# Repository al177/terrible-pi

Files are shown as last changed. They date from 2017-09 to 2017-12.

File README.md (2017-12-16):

# terrible-pi

 

*A supercomputer, but fun sized. And not super.*

In this repo you'll find hardware designs for the Terrible-Pi, a cluster
computer made from four Raspberry Pi Zero boards used as compute elements
and one Raspberry Pi Zero W as a head node and network router.

terrible-pi is based around a USB backplane that powers and interconnects
all five Pi Zeros and allows the head node to control power to each of the
compute nodes.  The USB boot feature of the Pi Zero is used to automate
deployment of new OS images to each compute node.

Up to date news on this project can be found at [this Hackaday project.](https://hackaday.io/project/27142-terrible-cluster)

Repo Contents
-------------
The terrible_pcb directory has a board design for the backplane and a 3D printable case.  See terrible_pcb/README for instructions for printing the case and the backplane board.

`etc` contains config files to be copied on top of the Raspbian install for
the head node.

wpa_supplicant.conf is a template WiFi config for the head node.  This is used
for headless setup of the head node Raspbian SD card for remote SSH access.

`nodeimg_build.sh` is a script for extracting a Raspbian distribution image into
a set of files used to deploy new compute nodes.

`node_init.sh` is a script used to upload the compute node Raspbian generated
by `nodeimg_build.sh` to the SD card of a compute node.

terrible-pi Install and Usage Guide
===================================

Setting up a terrible-pi cluster head node
------------------------------------------

1. Get the latest Raspbian (https://downloads.raspberrypi.org/raspbian_lite_latest)
   and install to a microSD
   
2. Mount the first (FAT) partition of the card on a PC.
		
3. Copy "wpa_supplicant.conf" from this repo to the card.  Edit it so that
   "YOUR_SSID" is replaced by the WiFi network name that you want the head node
   to connect to, and "YOUR_PASSPHRASE" is replaced by the network's key.  Use
   your Google-fu if you can't get it to work.
		
4. Create an empty file on the card named "ssh".  Use the UNIX command "touch
   ssh" or just open and save a new file "ssh" with your text editor.
		
5. Boot the microSD on the Pi Zero W
		
6. After 4-5 minutes, try SSHing as "pi" to the Zero W with the hostname
   "raspberrypi", "raspberrypi.lan", or "raspberrypi.local".  Use the password
   "raspberry".  If your router isn't serving DNS for local domains, you may
   have to check the router's DHCP lease logs to see what IP the head node has.
		
7. Now that you're logged into the Pi Zero W, update to the latest Raspbian
   packages:

```
sudo apt-get -y update && sudo apt-get -y upgrade
```
			
8. Install the necessary packages:
			
```
sudo apt-get -y install libusb-1.0-0-dev nfs-kernel-server git \
pdsh udhcpd iptables bridge-utils
```
9. Build and install the USB hub tool:

```
cd
git clone https://github.com/mvp/uhubctl.git
pushd uhubctl
make
sudo cp uhubctl /usr/local/bin/.
sudo chown root:root /usr/local/bin/uhubctl
popd
```
10. Build and install the USB boot tool:
	
```
git clone https://github.com/raspberrypi/usbboot.git
pushd usbboot
make
sudo cp rpiboot /usr/local/bin/.
sudo mkdir /usr/share/rpiboot
sudo cp -a msd /usr/share/rpiboot
sudo chown -R root:root /usr/share/rpiboot
sudo chown -R root:root /usr/local/bin/rpiboot
popd
```
11. Get this repo on the Pi:

```
git clone https://github.com/al177/terrible-pi.git
```

12. Copy the config files for the DHCP server, networks, NFS, SSH, and
hosts, hostname, and startup scripts:

```
sudo chown -R root:root /home/pi/terrible-pi/etc			
sudo cp -a /home/pi/terrible-pi/etc/* /etc/.
```		
13. Enable necessary services:

```
sudo systemctl enable udhcpd
sudo systemctl enable rpcbind
sudo systemctl enable nfs-kernel-server
```
14. Create an NFS directory for the clients:

```
sudo mkdir /srv/pihome
sudo chown pi:pi /srv/pihome
chmod 755 /srv/pihome
mkdir /srv/pihome/.ssh
chmod 700 /srv/pihome/.ssh
```

15. Reboot the head node.

16. SSH to the head node again. The config files copied over have changed the
    hostname to "head".  So if you connected as "raspberrypi.lan",
    "raspberrypi", or "raspberrypi.local" above, use "head.lan", "head", or
    "head.local" when reconnecting.

17. Make an empty passphrase SSH key so the head can automatically connect to
    the nodes:

```
ssh-keygen -t rsa -f /srv/pihome/.ssh/terrible.rsa -N ""
cp /srv/pihome/.ssh/terrible.rsa.pub /srv/pihome/.ssh/authorized_keys
chmod 600 /srv/pihome/.ssh/authorized_keys
mkdir -p ~/.ssh
chmod 700 ~/.ssh
cp /srv/pihome/.ssh/terrible.rsa ~/.ssh/.
```

Setting up terrible cluster compute nodes
-----------------------------------------

### Creating the compute node filesystem

1. Get the Raspbian Lite zip file on the head node in /home/pi.  This can be
   the zip used to create the head node microSD card, or can be downloaded by:

```
wget --trust-server-names https://downloads.raspberrypi.org/raspbian_lite_latest
```
	 
Note the filename that it downloads as.

2. Prep the boot image:

```
sudo terrible-pi/nodeimg_build.sh 2017-09-07-raspbian-stretch-lite.zip
```
	
This will take 10-15 minutes.  The result will be a directory "tcboot"
that contains the boot files and filesystems for the nodes.  This process
needs to be repeated only when changing or upgrading the Raspbian install on
the compute nodes.

### Deploying Raspbian to the compute nodes

1. Insure that the microSD cards in nodes do not contain the Raspberry Pi
   bootloader, or the USB boot method used to manage this cluster will not work.
   Insure that "bootcode.bin" does not exist in the root of any of the
   partitions on any of the cards.  If in doubt, do a full erase on the SD card
   to wipe out the bootloader in any of the partitions.
	 
2. Turn off all the nodes.  If the nodes all power up in bootstrap mode
   simultaneously, the image transfer script won't work.

```
sudo uhubctl -r 4 -a off
```

3. Transfer the SD filesystem to each node, looping over all nodes in series:

```
for N in 1 2 3 4; do sudo terrible-pi/node_init.sh tcboot $N; done
```

This takes 5-10 minutes per node depending on the speed of the SD cards
on the compute node Pi Zeros.

Terrible cluster management
---------------------------

### Booting the cluster

To boot the compute nodes, first start the rpiboot server in another
terminal session:

```
sudo rpiboot -o -l -d /home/pi/tcboot
```

Then cycle power on all of the nodes:

```
sudo uhubctl -r 4 -a cycle
```

The boot will take 2-3 minutes.  The nodes should be pingable once they are
done.  

### Connecting to the nodes

Before SSHing to a node in any given session, start the key agent and add
the SSH key:

```
eval `ssh-agent`
ssh-add ~/.ssh/terrible.rsa
```

You can SSH to a node by name:

```
ssh node1
```

Or you can run a command on all nodes with pdsh:

```
pdsh -R ssh -w node1,node2,node3,node4 hostname
```

Raspberry Pi Zero 1.3 models
[pi0computer.stl and pi0sdcard.stl](https://www.thingiverse.com/thing:2101674)
are created by jdhorvat and licensed CC-BY-NC.  [OpenSCAD parametric fan model](https://www.thingiverse.com/thing:625905) is created by GelatinousSlime and licensed CC-BY-SA. All other files in this tree are by Andrew Litt and licensed as 
[CC-BY-SA.](https://creativecommons.org/licenses/by-sa/4.0/)

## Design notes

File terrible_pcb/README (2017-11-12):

Hardware design for the Terrible Cluster.

1) Backplane board

terrible.pro is the KiCad project for the Terrible Cluster backplane board.  All components needed to create fabbable output are in this project, however due to license restrictions the 3D models needed to render the assembly are not included.

Pre-built gerbers for the v0.1 release of the board are in the directory gerber_v0.1.  These are fab-ready and can be zipped and sent off as-is.

terrible_v1a_bom.csv is a CSV format BOM for the backplane.  It can be imported to a Digi-Key cart for convenience.

BOM history
-----------
v1  - Initial BOM for PCB v0.1
v1a - Corrected microUSB B to match the current footprint, add insulator
      spacer for crystal Y1

After assembling the backplane, flush cut all of the through hole pins to under 1mm, or it may not fit in the case.

2) Case

terrible_case.scad is an OpenSCAD model for a 3D printed enclosure for the Terrible Cluster.  It is a single piece into which the backplane and Zero nodes can slide.  A 40mm x 40mm x 10mm 5V fan is friction-fit into the open end, and provides cooling for the cluster.  The cluster board assembly is held in place by a piece of 1.75mm filament fed through holes at the open side of the backplane PCB channel.

terrible_case.stl is a printable file for the case rendered from terrible_case.scad.  This case is sensitive to printer tolerances, so if parts of the case print too tight or loose, it may be necessary to customize the SCAD file and regenerate the .stl.

The fan is wired to the two pin power pads on the backplane.  A 2x1 0.1" right angle header can be soldered to the pads, and a matching plug attached to the fan leads if desired, or the fan can be soldered directly to the pads.  Care should be taken to reduce slack in the fan cable to prevent any loose wire from interfering with the fan.

When sliding the cluster into the case, it may be necessary to move the Zeros side to side to get them to all fit in the slot cutouts.  It should not take much force to get the backplane to slide in all the way.

After the cluster is in the case, feed a piece of 1.75mm filament through both holes towards the back of the case.  Use flush cutters to clip the filament even with the side of the case on both sides.  This will prevent the cluster from sliding backwards into the fan, especially when inserting a microUSB power cable.  To take apart the cluster, push the filament through with a paperclip and pull it out from the other side.

The fan uses a friction fit to hold it in the back of the case.  Exact outer dimensions of these fans can vary slightly, so the fan cutout is intentionally slightly oversized.  Use a piece of folded paper or layers of tape on one side of the fan as a shim to secure the fan.

The SCAD file can render the case alone in an orientation for printing, or render the case along with a model of the cluster and the fan to show the finished cluster.  Set "PRODUCTION=true" near the top of the SCAD to render for printing, and "PRODUCTION=false" to render the internal parts as well.

3) Cluster model

terrible.scad is an OpenSCAD model of the backplane board and the Raspberry Pi Zeros.  It is used as part of the case model for checking fitment and to render a completed Terrible Cluster.  Load it into OpenSCAD on its own to render the cluster boards.

Attributions:

-Raspberry Pi Zero model by MisterC from https://www.thingiverse.com/thing:1638529 for the 3D model.

-OpenSCAD parametric fan model by GelatinousSlime from https://www.thingiverse.com/thing:625905 for the case model.

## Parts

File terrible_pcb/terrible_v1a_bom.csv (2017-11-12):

Digi-Key Part Number | Manufacturer | Manufacturer Part Number | Customer Reference | Quantity 1 | Quantity 2 | Quantity 3 | Mfg Std Lead Time | Description | Comments | RoHS Status | Lead Free Status | REACH Status
H125237-ND | HIROSE ELECTRIC CO LTD | ZX20-B-5S-UNIT(30) | P1 | 5 | 0 | 0 | 8 Weeks | CONN PLUG USB MICRO B PCB VERT |  | RoHS Compliant | Lead free | Not Available
H11496CT-ND | HIROSE ELECTRIC CO LTD (VA) | ZX20-B-SLDC | P1 | 5 | 0 | 0 | 8 Weeks | SHIELDING PLATE FOR ZX20 PLUG | Alternate Packaging Exists | RoHS Compliant | Lead free | Not Available
428-3155-1-ND | CYPRESS SEMICONDUCTOR CORP (VA) | CY7C65632-48AXCT | U1 | 1 | 0 | 0 | 15 Weeks | IC CONTROLLER USB 48TQFP | Alternate Packaging Exists | RoHS Compliant | Lead free | Unaffected Jul-2017
AP2191DWG-7DICT-ND | DIODES INCORPORATED (VA) | AP2191DWG-7 | U2 | 4 | 0 | 0 | 12 Weeks | IC PWR SW USB SOT25 | Alternate Packaging Exists | RoHS Compliant | Lead free | Unaffected Jan-2017
P964-ND | PANASONIC ELECTRONIC COMPONENTS | ECE-A1AKS221 | C1 | 4 | 0 | 0 | 15 Weeks | CAP ALUM 220UF 20% 10V RADIAL |  | RoHS Compliant | Lead free | Unaffected Jun-2016
WM1399CT-ND | MOLEX, LLC (VA) | 1050170001 | P6 | 1 | 0 | 0 | 17 Weeks | CONN RCPT MICRO USB R/A SMD | Alternate Packaging Exists | RoHS Compliant | Lead free | Unaffected Jun-2016
535-9037-ND | ABRACON LLC | ABL-12.000MHZ-B2 | Y1 | 1 | 0 | 0 | 9 Weeks | CRYSTAL 12.0000MHZ 18PF T/H |  | RoHS Compliant | Lead free | Affected Jan-2017
311-1088-1-ND | YAGEO (VA) | CC0603KRX7R7BB104 | C* | 15 | 0 | 0 | 16 Weeks | CAP CER 0.1UF 16V X7R 0603 | Alternate Packaging Exists | RoHS Compliant | Lead free | Unaffected Jul-2017
1276-1946-1-ND | SAMSUNG ELECTRO-MECHANICS AMERICA, INC (VA) | CL10B105KP8NNNC | C13 | 3 | 0 | 0 | 18 Weeks | CAP CER 1UF 10V X7R 0603 | Alternate Packaging Exists | RoHS Compliant | Lead free | Unaffected Jul-2017
1276-1187-1-ND | SAMSUNG ELECTRO-MECHANICS AMERICA, INC (VA) | CL10C200JB8NNNC | C8 | 2 | 0 | 0 | 26 Weeks | CAP CER 20PF 50V C0G/NP0 0603 | Alternate Packaging Exists | RoHS Compliant | Lead free | Unaffected Jul-2017
1276-6456-1-ND | SAMSUNG ELECTRO-MECHANICS AMERICA, INC (VA) | CL21A106KPFNNNG | C7 | 1 | 0 | 0 | 26 Weeks | CAP CER 10UF 10V X5R 0805 | Alternate Packaging Exists | RoHS Compliant | Lead free | Unaffected Jul-2017
587-1932-1-ND | TAIYO YUDEN (VA) | BKP2125HS600-T | FB1 | 1 | 0 | 0 | 6 Weeks | FERRITE BEAD 60 OHM 0805 1LN | Alternate Packaging Exists | RoHS Compliant | Lead free | Not Available
311-10KGRCT-ND | YAGEO (VA) | RC0603JR-0710KL | R1 | 10 | 0 | 0 | 16 Weeks | RES SMD 10K OHM 5% 1/10W 0603 | Alternate Packaging Exists | RoHS Compliant | Lead free | Unaffected Jul-2017
311-649HRCT-ND | YAGEO (VA) | RC0603FR-07649RL | R9 | 1 | 0 | 0 | 16 Weeks | RES SMD 649 OHM 1% 1/10W 0603 | Alternate Packaging Exists | RoHS Compliant | Lead free | Unaffected Jul-2017
311-47KGRCT-ND | YAGEO (VA) | RC0603JR-0747KL | R7 | 1 | 0 | 0 | 16 Weeks | RES SMD 47K OHM 5% 1/10W 0603 | Alternate Packaging Exists | RoHS Compliant | Lead free | Unaffected Jul-2017
XC1750-ND | ECS INC | 700-TFL-9001 | Y1 | 1 | 0 | 0 | 3 Weeks | CRYSTAL INSULATOR HC-49U/US |  | RoHS Compliant | Lead free | Unaffected Jun-2016

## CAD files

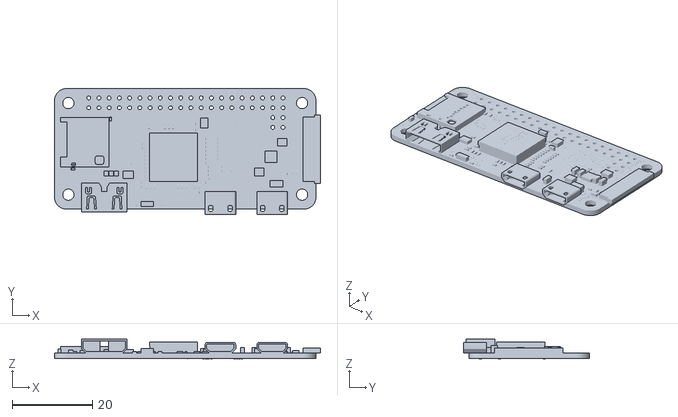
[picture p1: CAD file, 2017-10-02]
terrible_pcb/pi0computer.stl
66.1 x 31.3 x 4.85

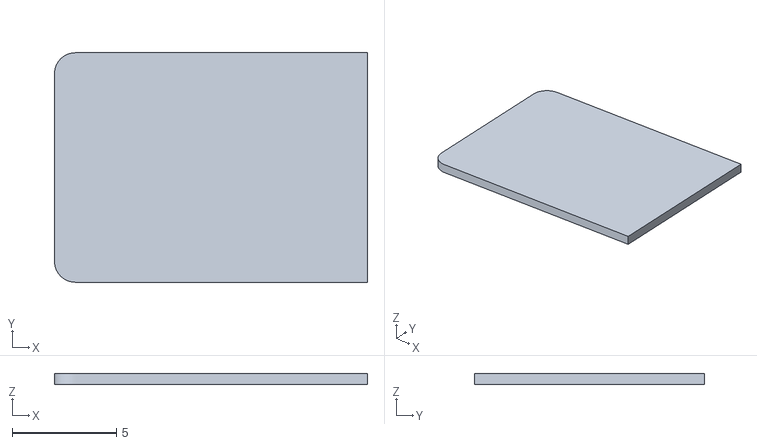
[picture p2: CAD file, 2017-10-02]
terrible_pcb/pi0sdcard.stl
15.0 x 11.0 x 0.55

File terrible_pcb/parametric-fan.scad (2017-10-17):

// Remixed from MiseryBot's original work: http://www.thingiverse.com/thing:8063

$fn=60;  //Working
//$fn=720;  //Show off
fan(40, 10, 32, 4.3);

module fan(width, depth, mount, mount_diameter=3.4, corner_radius=5, blade_angle=-45)
{
  bore_diameter = width - 3;

  color ("dimgrey")
  {
    body(width, depth, bore_diameter, mount, mount_diameter, corner_radius);
    fan_blades(bore_diameter, depth, blade_angle);
  }
}

module body(width, depth, bore_diameter, mount, mount_diameter, corner_radius)
{
  difference()
  {
    linear_extrude(height=depth, center = true, convexity = 4, twist = 0)
    {
      difference()
      {
        square([width, width], center=true);
        inside_bore(bore_diameter, width/2 + 2);
        mounting_holes(mount/2, mount_diameter/2, depth+0.2);
        round_corners(width/2, corner_radius);
      }
    }

    outside_ring(width, depth);
  }
}

module inside_bore(diameter, hub)
{
  difference()
  {
    circle(r=diameter/2,center=true);
    circle(r=hub/2,center=true);
  }
}

module mounting_holes(offset, r, h)
{
  for (i=[0:3])
  {
    rotate([0,0,i*90])
    {
      translate([offset, offset])
      {
        circle(r=r, h=h, center=true);
      }
    }
  }
}

module round_corners(offset, r=5)
{
  for(i=[0:3])
  {
    rotate([0,0,i*90])
    {
      translate([offset,offset])
      {
        difference()
        {
          translate([-r+0.1, -r-0.1])
          {
            square([r+0.2, r+0.2]);
          }

          translate([-r, -r])
          {
            circle(r=r);
          }
        }
      }
    }
  }
}

module outside_ring(width, depth, surface_thickness=3.6)
{
  difference()
  {
    cylinder(r=width*.75, h=depth-2*surface_thickness, center=true);
    cylinder(r=(width+2)/2, h=depth-2*surface_thickness+0.2, center=true);
  }
}

module fan_blades(width, depth, angle)
{
  linear_extrude(height=depth-1, center = true, convexity = 4, twist = angle)
  {
    for(i=[0:6])
    rotate((360*i)/7)
    translate([0,-1.5/2]) square([width/2-0.75,1.5]);
  }
}

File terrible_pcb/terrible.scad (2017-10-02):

PI_SLOT_SPACING=6;

module terrible_backplane() {
	translate([129.55,-76.46,0.4]) rotate([0,0,180]) import("terrible.stl",convexity=3);
}

module pi_zeros() {

	for(pi_slot=[0:4])
	{
		translate([32.55+(pi_slot*PI_SLOT_SPACING),114.83,-39.8]) rotate([90,0,-90]) {
			import( "pi0computer.stl",convexity=3);
			translate([24.7,0,4.8])
				import( "pi0sdcard.stl",convexity=3);
		}
	}
}

terrible_backplane();
%pi_zeros();

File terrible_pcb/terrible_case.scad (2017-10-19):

use <terrible.scad>;
use <parametric-fan.scad>;

// Set true to render for printing
PRODUCTION=true;

SHOW_INNARDS=true;

if(SHOW_INNARDS && !PRODUCTION) {
    translate([0,PCB_EDGE_Y_EXTRA,0]) {
        #terrible_backplane();
        #pi_zeros();
    } 
    translate([PCB_EDGE_X/2,-FAN_THICK/2-FAN_PI_BACK_GAP-0.01,FAN_Z_OFS-PCB_BOT_CLEARANCE/2]) rotate([90,0,0]) fan(FAN_WIDTH, FAN_THICK, 32, 4.3);

}

X_EDGE_TO_HEAD_NODE_TOP=6.5;

PCB_EDGE_X=38;
PCB_EDGE_X_CLEARANCE=0.8;
PCB_EDGE_Y_EXTRA=0;
PCB_EDGE_Y=65.3;
PCB_EDGE_Z=0.8;
PCB_EDGE_Z_CLEARANCE=0.2;
PCB_BOT_CLEARANCE=0.8;


PI_BOT=9.4; /* top of PCB to bottom of Pi */
PI_WIDTH=30.0;
PI_WIDTH_CLEARANCE=.8;

PI_CAM_HDR_WIDTH=17.5;
PI_CAM_HDR_HEIGHT=1.4;
PI_CAM_HDR_FROM_EDGE=6.2;

PI_ZERO_BOARD_EDGE_OFS_FROM_0=8.02;
PI_ZERO_BOARD_TOP_OFS_FROM_4=4.58;
PI_ZERO_BOARD_TOP_CLEARANCE=6;
PI_ZERO_BOARD_THICK=1.4;

INT_HEIGHT=PCB_EDGE_Z+PI_BOT+PI_WIDTH+PI_WIDTH_CLEARANCE/2;

SDCARD_WIDTH=12.3;
SDCARD_EXT=4;
SDCARD_FROM_EDGE=10.5;
SDCARD_THICK=2.5;
SDCARD_Z_FUDGE=0.4;

SD_VENT_WIDTH=19;
SD_VENT_EXT=4;
SD_VENT_FROM_EDGE=6.5;
SD_VENT_THICK=5;
SD_VENT_Z_FUDGE=-0.5;

USB_FROM_0=15;
USB_WIDTH=8.1;
USB_HEIGHT=3.6;
USB_EXT=4;
USB_Z_FUDGE=0.5;

USB_INSET_DEPTH=1.2;
USB_INSET_ADDL_W=3.4;
USB_INSET_ADDL_H=3.4;

CASE_THICK=2.5;

PI_LOWER_CRADLE_L=5;
PI_LOWER_CRADLE_H=4;
PI_LOWER_CRADLE_NOTCH=2;

PI_UPPER_CRADLE_L=6;
PI_UPPER_CRADLE_H=3;

/* Dimensions for standard 40x40x10 box fan */
FAN_THICK=10;
FAN_WIDTH=40;
FAN_HOLE_SPACE=36;

FAN_PI_BACK_GAP=3;
FAN_END_Z_OFS=2;
FAN_CLEARANCE=0.6;
FAN_CASE_INNER_WIDTH=FAN_WIDTH+FAN_CLEARANCE;

FAN_CASE_INSET=FAN_PI_BACK_GAP+FAN_THICK;
FAN_X_OFFSET=(FAN_WIDTH-PCB_EDGE_X)/2;

FAN_Z_OFS=FAN_WIDTH/2;

SEAM_FROM_BACK=10;

PI_SLOT_SPACING=6;

SECURING_PIN_DIA=2.1; //guess at dia for 1.75mm
SECURING_PIN_Y_EXTRA=0.4; //amount to nudge closer to PCB edge


if(PRODUCTION) {
    translate([FAN_X_OFFSET+FAN_CLEARANCE/2+CASE_THICK, CASE_THICK+PCB_EDGE_Z+PCB_BOT_CLEARANCE,PCB_EDGE_Y+CASE_THICK])
        rotate([-90,0,0]) case_body();
} else {
    case_body();
}

module case_body() {
    difference() {
        hull() {
            outer_shape_curvy();
            //fan_end();
            fan_end_minimal();
        }
        
        
        
        difference()
        {
            inner_bulk_cutout();
            
            zero_lower_cradle();
            zero_upper_cradle_far();
        }
        
        inner_pcb_cutout();
        fan_cutout();
        sd_vent_cutouts();
        usb_cutout();
        securing_pins_cutout();
        
    }
}



module outer_shape() {
    translate([-CASE_THICK, -(CASE_THICK), -(CASE_THICK+PCB_BOT_CLEARANCE)] )
        minkowski() {
            cube([CASE_THICK*2+PCB_EDGE_X,CASE_THICK*2+PCB_EDGE_Y,CASE_THICK*2+INT_HEIGHT+PCB_BOT_CLEARANCE]);
        sphere(r=0.01, $fn=32);
    }
}

module outer_shape_curvy() {
    
    minkowski() {
        inner_bulk_cutout();
        sphere(CASE_THICK,$fn=32);
    }

}

module inner_bulk_cutout() {
    union()
    {
        translate([0, 0, -PCB_BOT_CLEARANCE] ) 
            cube([PCB_EDGE_X, PCB_EDGE_Y,PCB_EDGE_Z+PI_BOT+PCB_BOT_CLEARANCE]);
        
        translate([PI_ZERO_BOARD_EDGE_OFS_FROM_0-PI_ZERO_BOARD_TOP_CLEARANCE,0,PI_BOT])
        cube([PI_ZERO_BOARD_TOP_CLEARANCE+PI_ZERO_BOARD_THICK+24,PCB_EDGE_Y,INT_HEIGHT-PI_BOT]);
    }
}

module fan_cutout() {
    union()
    {
        translate([0, -FAN_CASE_INSET, -PCB_BOT_CLEARANCE] ) 
            cube([PCB_EDGE_X, PCB_EDGE_Y,PCB_EDGE_Z+PI_BOT+PCB_BOT_CLEARANCE]);
        translate([-PCB_EDGE_X_CLEARANCE/2, -FAN_CASE_INSET, -PCB_EDGE_Z_CLEARANCE/2] ) 
            cube([PCB_EDGE_X+PCB_EDGE_X_CLEARANCE, PCB_EDGE_Y+PCB_EDGE_Y_EXTRA,PCB_EDGE_Z+PCB_EDGE_Z_CLEARANCE]);
        
        translate([PI_ZERO_BOARD_EDGE_OFS_FROM_0-PI_ZERO_BOARD_TOP_CLEARANCE,-FAN_CASE_INSET,PI_BOT])
        cube([PI_ZERO_BOARD_TOP_CLEARANCE+PI_ZERO_BOARD_THICK+24,PCB_EDGE_Y,INT_HEIGHT-PI_BOT]);
    
        translate([-FAN_X_OFFSET-FAN_CLEARANCE/2, -FAN_THICK-FAN_PI_BACK_GAP-5, -PCB_BOT_CLEARANCE])
            cube([FAN_CASE_INNER_WIDTH, FAN_THICK+4, FAN_CASE_INNER_WIDTH]);
    }
}

module inner_pcb_cutout() {
translate([-PCB_EDGE_X_CLEARANCE/2, 0, -PCB_EDGE_Z_CLEARANCE/2] ) 
            cube([PCB_EDGE_X+PCB_EDGE_X_CLEARANCE, PCB_EDGE_Y+PCB_EDGE_Y_EXTRA,PCB_EDGE_Z+PCB_EDGE_Z_CLEARANCE]);
 }

module sdcard_cutouts() {
    for(pi_slot=[0:4]) {
        translate([PI_ZERO_BOARD_EDGE_OFS_FROM_0+(pi_slot*PI_SLOT_SPACING)+SDCARD_Z_FUDGE-SDCARD_THICK-PI_ZERO_BOARD_THICK, PCB_EDGE_Y-1, SDCARD_FROM_EDGE+PI_BOT+PCB_EDGE_Z])
            cube([SDCARD_THICK,SDCARD_EXT,SDCARD_WIDTH]);
    }
}

module sd_vent_cutouts() {
    for(pi_slot=[0:4]) {
        translate([PI_ZERO_BOARD_EDGE_OFS_FROM_0+(pi_slot*PI_SLOT_SPACING)+SD_VENT_Z_FUDGE-(SD_VENT_THICK/2)-PI_ZERO_BOARD_THICK, PCB_EDGE_Y-1, SD_VENT_FROM_EDGE+PI_BOT+PCB_EDGE_Z])
            cube([SD_VENT_THICK,SD_VENT_EXT,SD_VENT_WIDTH]);
    }
}

module usb_cutout() {
    union() {
        translate([USB_FROM_0, PCB_EDGE_Y-1, PCB_EDGE_Z-USB_Z_FUDGE])
            cube([USB_WIDTH, USB_EXT, USB_HEIGHT+USB_Z_FUDGE]);
        translate([USB_FROM_0-USB_INSET_ADDL_W/2,PCB_EDGE_Y+CASE_THICK-USB_INSET_DEPTH, PCB_EDGE_Z-USB_Z_FUDGE-USB_INSET_ADDL_H/2])
            cube([USB_WIDTH+USB_INSET_ADDL_W, USB_INSET_DEPTH*2, USB_HEIGHT+USB_Z_FUDGE+USB_INSET_ADDL_W]);
    }
}

module zero_lower_cradle() {
    difference() {
    translate([-0.01, PCB_EDGE_Y-PI_LOWER_CRADLE_L, PCB_EDGE_Z+PI_BOT-PI_LOWER_CRADLE_H+PI_LOWER_CRADLE_NOTCH+0.01] ) 
            cube([PCB_EDGE_X+0.02, PI_LOWER_CRADLE_L+0.01,PI_LOWER_CRADLE_H]);
    for(pi_slot=[0:4]) {
        translate([PI_ZERO_BOARD_EDGE_OFS_FROM_0+(pi_slot*PI_SLOT_SPACING)-PI_ZERO_BOARD_THICK-0.2, PCB_EDGE_Y-PI_LOWER_CRADLE_L-0.01, PCB_EDGE_Z+PI_BOT-PI_WIDTH_CLEARANCE/2+0.01])
            cube([PI_ZERO_BOARD_THICK+0.4,PI_LOWER_CRADLE_L+0.01,PI_LOWER_CRADLE_NOTCH+PI_WIDTH_CLEARANCE/2+0.01]);
    }
    }
}

module zero_upper_cradle_far() {
    difference() {
    translate([-0.01, PCB_EDGE_Y-PI_UPPER_CRADLE_L, INT_HEIGHT-PI_UPPER_CRADLE_H+0.01] ) 
            cube([PCB_EDGE_X+0.02, PI_UPPER_CRADLE_L+0.01,PI_UPPER_CRADLE_H]);
    for(pi_slot=[0:4]) {
        translate([PI_ZERO_BOARD_EDGE_OFS_FROM_0+(pi_slot*PI_SLOT_SPACING)-PI_ZERO_BOARD_THICK-0.2, PCB_EDGE_Y-PI_UPPER_CRADLE_L-0.01, INT_HEIGHT-PI_UPPER_CRADLE_H-0.01])
            cube([PI_ZERO_BOARD_THICK+0.4,PI_UPPER_CRADLE_L+0.01,PI_UPPER_CRADLE_H+PI_WIDTH_CLEARANCE/2+0.01]);
    }
    }
}

module fan_end() {
     difference() {
        translate([-CASE_THICK/2,-FAN_THICK-FAN_PI_BACK_GAP,-PCB_BOT_CLEARANCE])
         minkowski() {
            cube([FAN_CASE_INNER_WIDTH,FAN_THICK+FAN_PI_BACK_GAP,FAN_CASE_INNER_WIDTH]);
            sphere(CASE_THICK,$fn=32);
        }
        translate([-CASE_THICK/2, -FAN_THICK-FAN_PI_BACK_GAP, -PCB_BOT_CLEARANCE])
            cube([FAN_CASE_INNER_WIDTH, FAN_THICK, FAN_CASE_INNER_WIDTH]);
        BORE_WIDTH=FAN_WIDTH-4.5;
        translate([PCB_EDGE_X/2,-FAN_THICK-0.01,FAN_Z_OFS]) rotate([90,0,0]) cylinder(r=BORE_WIDTH/2, h=20,$fn=32);
    }
}

module fan_end_minimal() {
     
        translate([-FAN_X_OFFSET-FAN_CLEARANCE/2,-FAN_THICK-FAN_PI_BACK_GAP+CASE_THICK,-PCB_BOT_CLEARANCE])
         minkowski() {
            cube([FAN_CASE_INNER_WIDTH,FAN_THICK+FAN_PI_BACK_GAP-CASE_THICK,FAN_CASE_INNER_WIDTH]);
            sphere(CASE_THICK,$fn=32);
        }
}

module securing_pins_cutout() {
    translate([-FAN_X_OFFSET-FAN_CLEARANCE/2-CASE_THICK-0.01,-SECURING_PIN_DIA/2+PCB_EDGE_Y_EXTRA+SECURING_PIN_Y_EXTRA,PCB_EDGE_Z/2])
    rotate([0,90,0])
        cylinder(d=SECURING_PIN_DIA, h=FAN_CASE_INNER_WIDTH+CASE_THICK*2+0.01, $fn=32);
}

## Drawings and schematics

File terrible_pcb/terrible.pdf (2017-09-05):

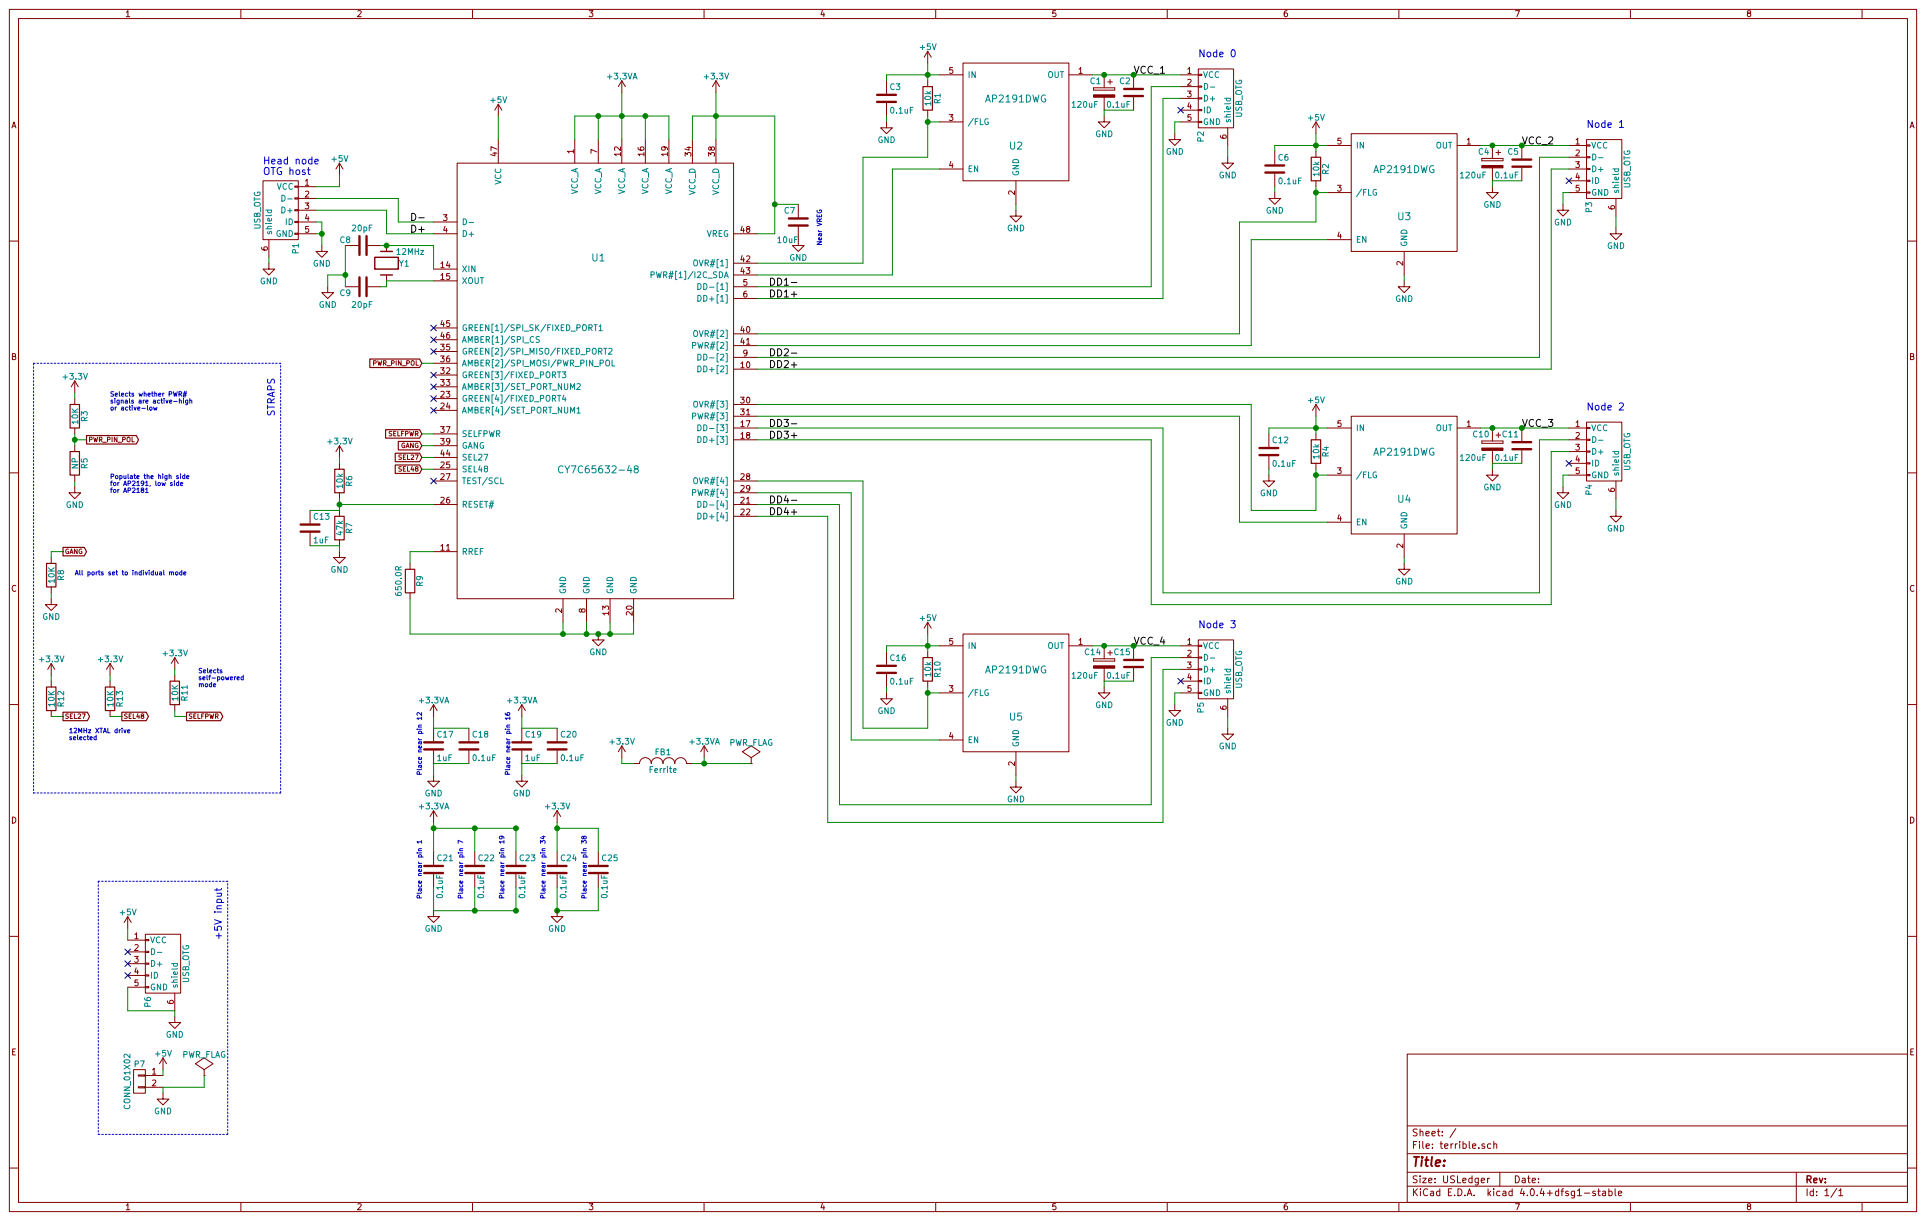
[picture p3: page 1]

or active-low GANG R8 10K GND

for AP2181 Selects whether PWR#
signals are active-high

Populate the high side
for AP2191, low side

All ports set to individual mode SEL48 10K R13 +3.3V

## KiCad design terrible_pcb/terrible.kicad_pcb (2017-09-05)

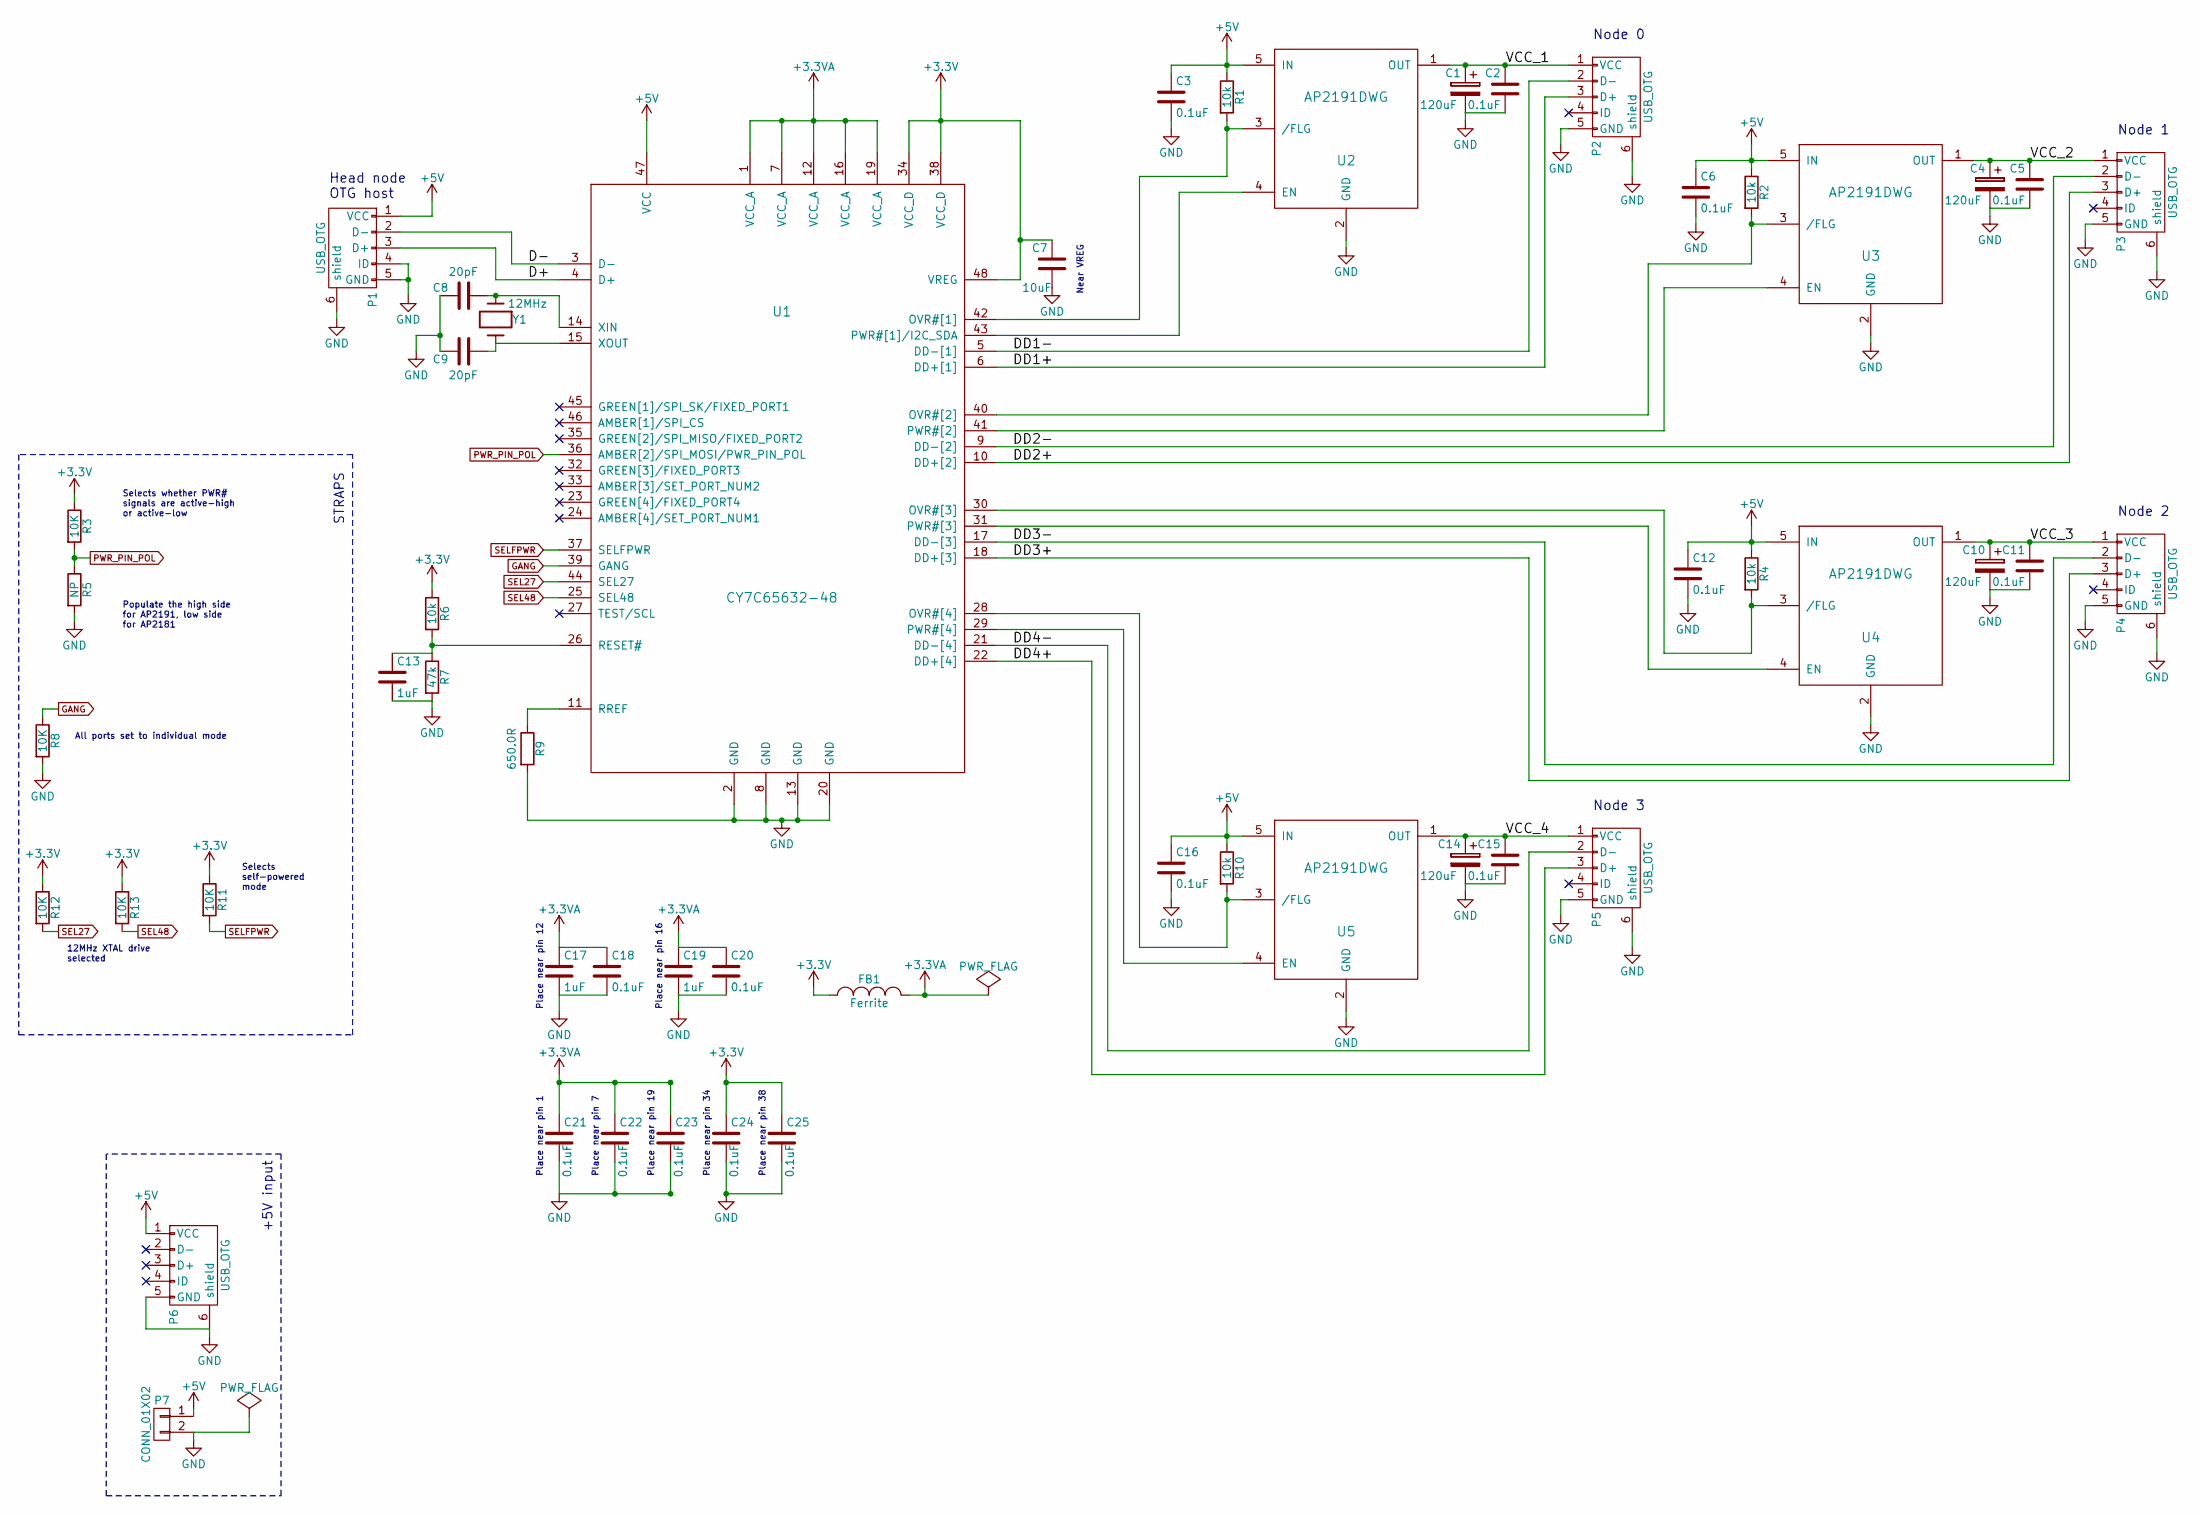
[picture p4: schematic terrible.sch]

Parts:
C1, C4, C10, C14: 120uF; C_Radial_D5_L11_P2.5
C2, C3, C5, C6, C11, C12, C15, C16, C18, C20, C21, C22, C23, C24, C25: 0.1uF; C_0805_HandSoldering
C7: 10uF; C_Radial_D5_L11_P2.5
C8, C9: 20pF; C_0805_HandSoldering
C13, C17, C19: 1uF; C_0805_HandSoldering
FB1: Ferrite; Choke_SMD_1206_Handsoldering
P1, P2, P3, P4, P5: USB_OTG; USB_Micro-B
P6: USB_OTG; USB_Micro-B_10103594-0001LF
P7: CONN_01X02; Pin_Header_Angled_1x02
R1, R2, R4, R6, R10: 10k; R_0603_HandSoldering
R3, R8, R11, R12, R13: 10K; R_0603_HandSoldering
R5: NP; R_0603_HandSoldering
R7: 47k; R_0603_HandSoldering
R9: 650.0R; R_0603_HandSoldering
U1: CY7C65632-48; TQFP-48_7x7mm_Pitch0.5mm
U2, U3, U4, U5: AP2191DWG; SOT-23-5
Y1: 12MHz; Crystal_HC49-SD_SMD

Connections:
+3.3VA: C17.1, C18.1, C19.1, C20.1, C21.1, C22.1, C23.1, FB1.1, U1.1 (VCC_A), U1.7 (VCC_A), U1.12 (VCC_A), U1.16 (VCC_A), U1.19 (VCC_A)
+3V3: C7.1, C24.1, C25.1, FB1.2, R3.1, R6.1, R11.1, R12.1, R13.1, U1.34 (VCC_D), U1.38 (VCC_D), U1.48 (VREG)
+5V: C3.1, C6.1, C12.1, C16.1, P1.1 (VCC), P6.1 (VCC), P7.1, R1.1, R2.1, R4.1, R10.1, U1.47 (VCC), U2.5 (IN), U3.5 (IN), U4.5 (IN), U5.5 (IN)
/D+: P1.3 (D+), U1.4 (D+)
/D-: P1.2 (D-), U1.3 (D-)
/DD1+: P2.3 (D+), U1.6 (DD+[1])
/DD1-: P2.2 (D-), U1.5 (DD-[1])
/DD2+: P3.3 (D+), U1.10 (DD+[2])
/DD2-: P3.2 (D-), U1.9 (DD-[2])
/DD3+: P4.3 (D+), U1.18 (DD+[3])
/DD3-: P4.2 (D-), U1.17 (DD-[3])
/DD4+: P5.3 (D+), U1.22 (DD+[4])
/DD4-: P5.2 (D-), U1.21 (DD-[4])
/VCC_1: C1.1, C2.1, P2.1 (VCC), U2.1 (OUT)
/VCC_2: C4.1, C5.1, P3.1 (VCC), U3.1 (OUT)
/VCC_3: C10.1, C11.1, P4.1 (VCC), U4.1 (OUT)
/VCC_4: C14.1, C15.1, P5.1 (VCC), U5.1 (OUT)
GANG: R8.1, U1.39 (GANG)
GND: C1.2, C2.2, C3.2, C4.2, C5.2, C6.2, C7.2, C8.2, C9.2, C10.2, C11.2, C12.2, C13.2, C14.2, C15.2, C16.2, C17.2, C18.2, C19.2, C20.2, C21.2, C22.2, C23.2, C24.2, C25.2, P1.4 (ID), P1.5 (GND), P1.6 (shield), P2.5 (GND), P2.6 (shield), P3.5 (GND), P3.6 (shield), P4.5 (GND), P4.6 (shield), P5.5 (GND), P5.6 (shield), P6.5 (GND), P6.6 (shield), P7.2, R5.2, R7.2, R8.2, R9.2, U1.2 (GND), U1.8 (GND), U1.13 (GND), U1.20 (GND), U2.2 (GND), U3.2 (GND), U4.2 (GND), U5.2 (GND)
unnamed: C8.1, U1.14 (XIN), Y1.1
unnamed: C9.1, U1.15 (XOUT), Y1.2
unnamed: C13.1, R6.2, R7.1, U1.26 (RESET#)
unnamed: R1.2, U1.42 (OVR#[1]), U2.3 (/FLG)
unnamed: R2.2, U1.40 (OVR#[2]), U3.3 (/FLG)
unnamed: R4.2, U1.30 (OVR#[3]), U4.3 (/FLG)
unnamed: R9.1, U1.11 (RREF)
unnamed: R10.2, U1.28 (OVR#[4]), U5.3 (/FLG)
unnamed: U1.29 (PWR#[4]), U5.4 (EN)
unnamed: U1.31 (PWR#[3]), U4.4 (EN)
unnamed: U1.41 (PWR#[2]), U3.4 (EN)
unnamed: U1.43 (PWR#[1]/I2C_SDA), U2.4 (EN)
PWR_PIN_POL: R3.2, R5.1, U1.36 (AMBER[2]/SPI_MOSI/PWR_PIN_POL)
SEL27: R12.2, U1.44 (SEL27)
SEL48: R13.2, U1.25 (SEL48)
SELFPWR: R11.2, U1.37 (SELFPWR)

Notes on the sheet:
Head node OTG host
Node 0
Node 1
Node 2
Node 3
Populate the high side for AP2191, low side for AP2181
Selects whether PWR# signals are active-high or active-low
All ports set to individual mode
12MHz XTAL drive selected
Selects self-powered mode
STRAPS
Place near pin 12
Place near pin 16
Place near pin 1
Place near pin 7
Place near pin 19
Place near pin 34
Place near pin 38
Near VREG
+5V input

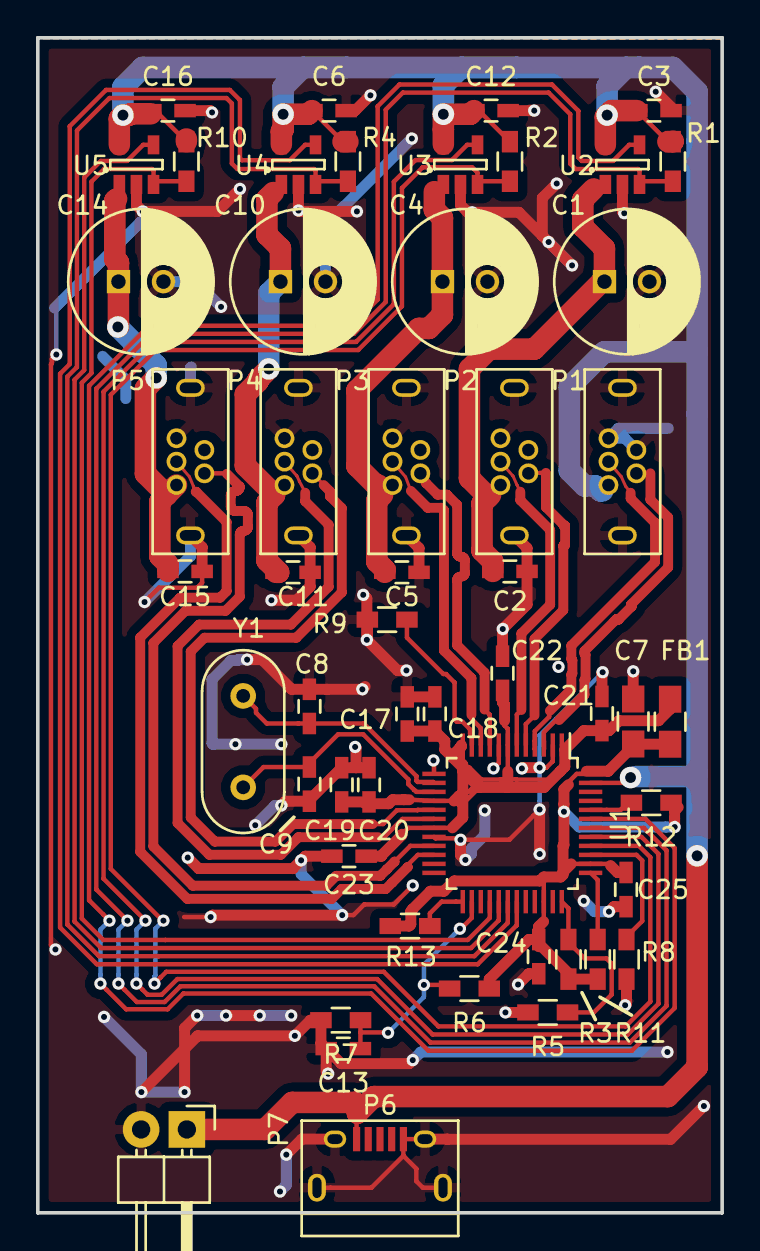
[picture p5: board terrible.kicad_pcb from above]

Board: 2 copper layers, 38.0 x 65.3 mm, 52 parts (0 on the bottom side), 35 nets.

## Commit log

2017-09-05 Initial commit. Includes first pass PCB gerbers
    [PiZero_1.2.stl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]
2017-09-05 Add README with Pi Zero model attribution, render, and schematic PDF.
    [terrible.kicad_pcb, terrible.scad]
2017-10-02 Remove old model
    [PiZero_1.2.stl, terrible.scad]
2017-10-02 Start on printed case
    [pi0computer.stl, pi0sdcard.stl, terrible.scad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]
2017-10-16 Case in progress checkpoint
    [terrible_case.scad]
2017-10-17 Add fan to enclosure, still not complete
    [terrible_case.scad]
2017-10-17 Add parametric DC box fan model
    [parametric-fan.scad]
2017-10-19 Integrated fan case
    [terrible_case.scad]
2017-10-19 Case and PCB documentation updates
2017-10-19 Add the DigiKey BOM
    [terrible_v1_bom.csv]
2017-10-19 Update build directions to use mainline usbboot
    The devicetree overlay directory support for usbboot has been merged to the mainline from burtyb's repo, so use mainline instead.
2017-10-20 Switch to the lightweight udhcpd package for the DHCP server
2017-11-12 microUSB-B connector in BOM now fits the PCB
    [terrible_v1_bom.csv]
2017-11-12 Update BOM version, add spacer for crystal
    [terrible_v1a_bom.csv]
2018-01-24 Increase USB MTU for jumbo frames, automatically find keyfile when sshing between nodes
2018-01-25 Linux RNDIS gadget and device driver goes to 15000, so crank it up
2020-10-18 Fixes to HPL procedures & switch to openmpi from MPICH due to segfaults from MPICH
